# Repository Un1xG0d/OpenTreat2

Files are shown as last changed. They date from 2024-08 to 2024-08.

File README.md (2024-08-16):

<h1 align="center">
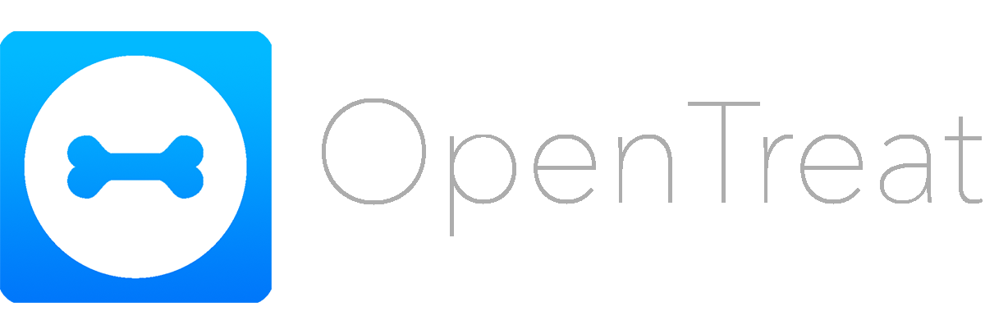
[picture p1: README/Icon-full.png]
  
</h1>

OpenTreat allows you to view and interact with your pets while not at home. 

Watch a live video stream of your pet from your smartphone or laptop, and remotely dispense treats with the push of a button.

This a complete rewrite of my original OpenTreat project found [here](https://github.com/Un1xG0d/OpenTreat-legacy).

## Overview
The treat dispenser system is built using a Raspberry Pi and 3D printed parts. When a user presses the button on the web app, it turns the servo motor for a certain number of seconds. This spins the middle piece and dispenses a section of treats into the bowl below.

## Parts needed
* Raspberry Pi
* SG90 servo (or any 360* servo motor)
* USB webcam
* 3D printer

## Physical assembly
1. Download and 3D print each STL listed in the `models` folder
	1. The recommended print settings are in the Resources section below
2. Assemble the parts using super glue
3. Hook up the 3 servo wires to the Raspberry Pi’s GPIO pins
	1. The proper pinout is in the Resources section below

## Device setup
1. Image your Raspberry Pi with [Raspbian](https://www.raspberrypi.com/software/)
2. Create a new user with the username `admin`
3. Configure your WiFi network settings
4. Enable OpenSSH

## Download the code
```
git clone https://github.com/Un1xG0d/OpenTreat.git ~/OpenTreat
cd ~/OpenTreat
```

## Install dependencies
```
sudo pip3 install -r requirements.txt
```

## Set up username and password
The web app uses HTTP Basic Auth to secure the video feed.

Create a `.env` file in the root directory and update the values accordingly:
```
USERNAME=test
PASSWORD=test
```

This will be your username & password to login to the web app.

## Automatic startup
Create a cronjob with `sudo crontab -e` to automatically set up and start the web app on boot.

```
@reboot /home/admin/OpenTreat/boot.sh
```

## Port forward the app
Make sure to change your router settings to allow a port forward of port 3000 to your Raspberry Pi. This is what makes the web app accessible to the internet.

## View the video stream
On your smartphone or laptop, browse to your router's external IP on port 3000 to view the video stream of your pets. Press the button to drop treats into your pets' bowl.

## Resources
### Recommended print settings
> Scale: 100%  
> Infill: 10%  
> Layer Height: 0.2  
> Speed: Standard  
> Supports: None

### RPi GPIO pinout
> Red wire - Pin 1 - 3v3 power  
> Black wire - Pin 6 - ground  
> Orange wire - Pin 11 - GPIO 17  

## Pictures & screenshots
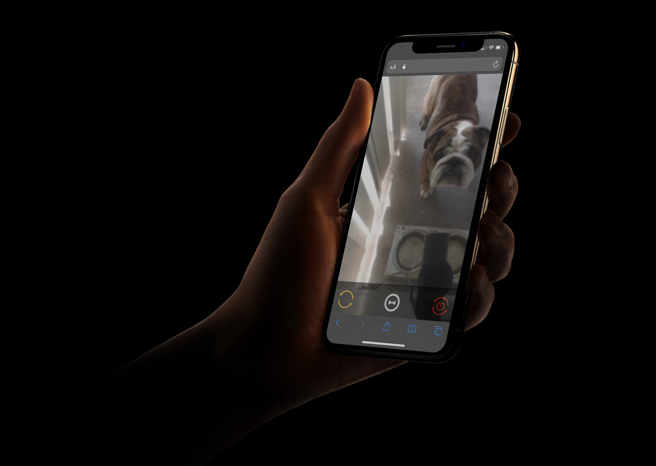
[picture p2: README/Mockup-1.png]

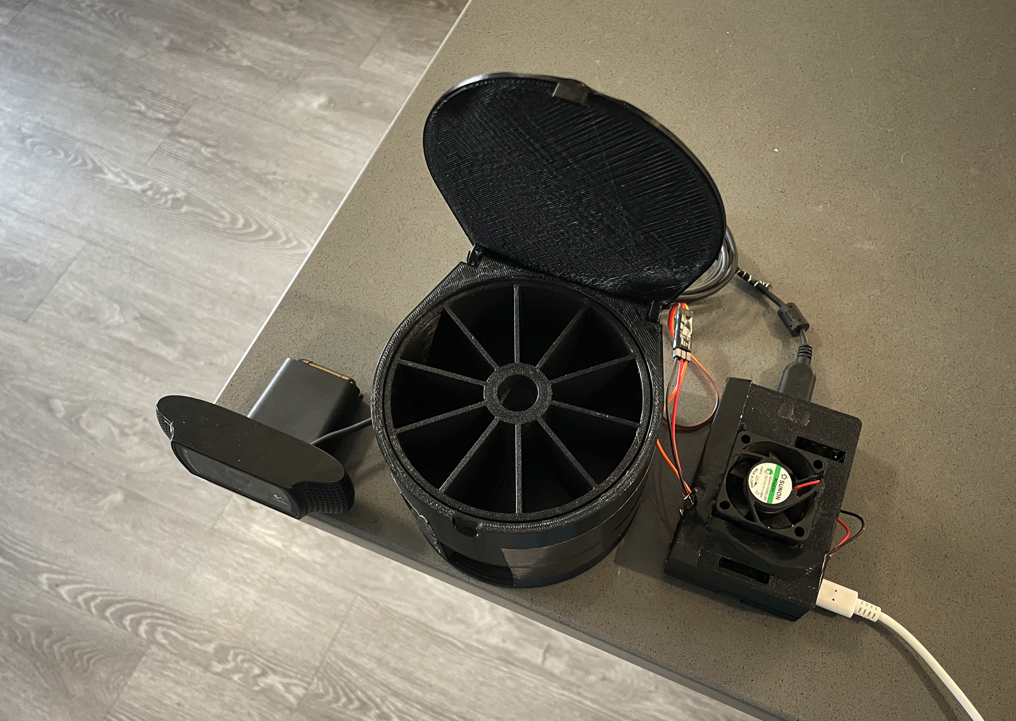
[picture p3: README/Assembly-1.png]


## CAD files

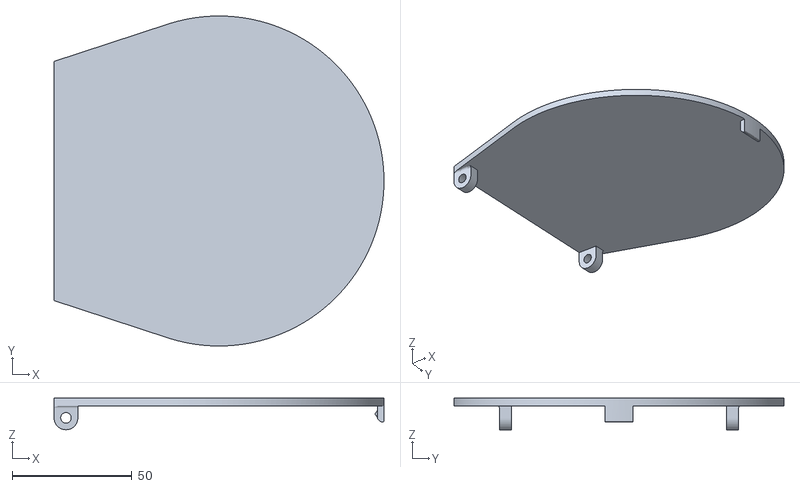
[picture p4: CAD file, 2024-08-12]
models/feeder_lid.stl
138.0 x 138.0 x 13.2

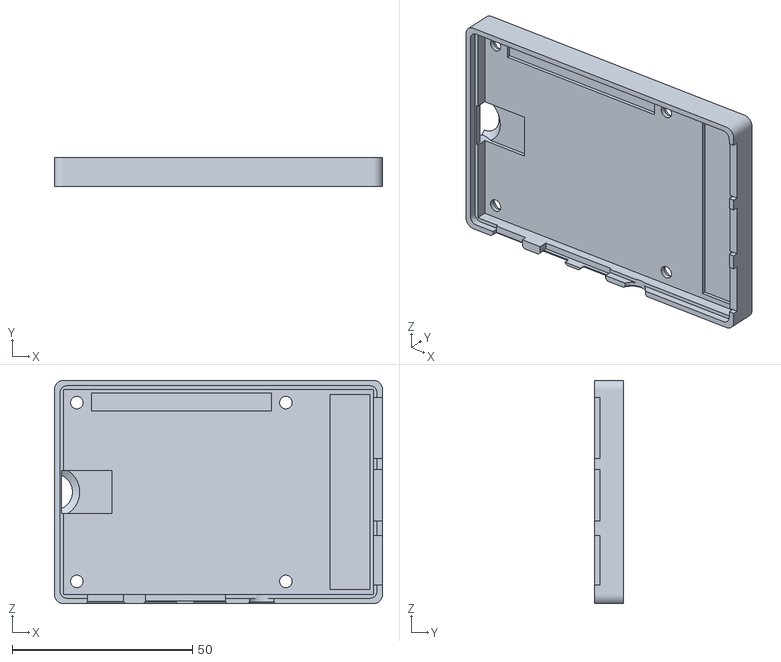
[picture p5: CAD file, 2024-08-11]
models/case_lower.stl
91.0 x 8.00 x 62.0

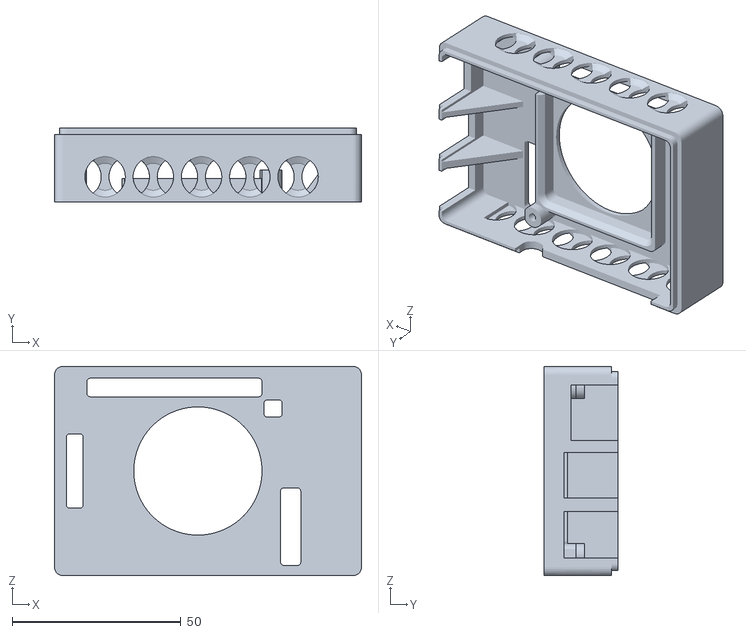
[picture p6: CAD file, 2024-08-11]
models/case_upper.stl
91.0 x 22.0 x 62.0

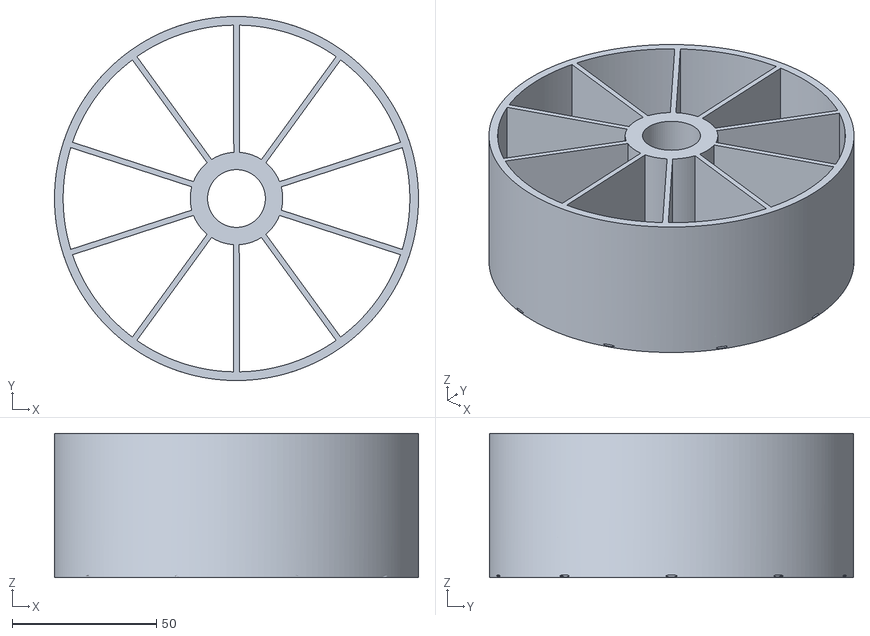
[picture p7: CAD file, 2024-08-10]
models/feeder_supply.stl
126.0 x 126.0 x 50.0

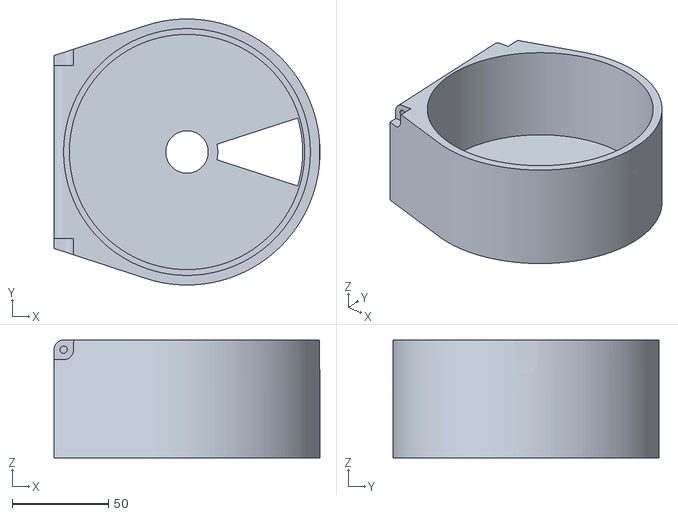
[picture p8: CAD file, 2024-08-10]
models/feeder_top.stl
138.0 x 138.0 x 61.2

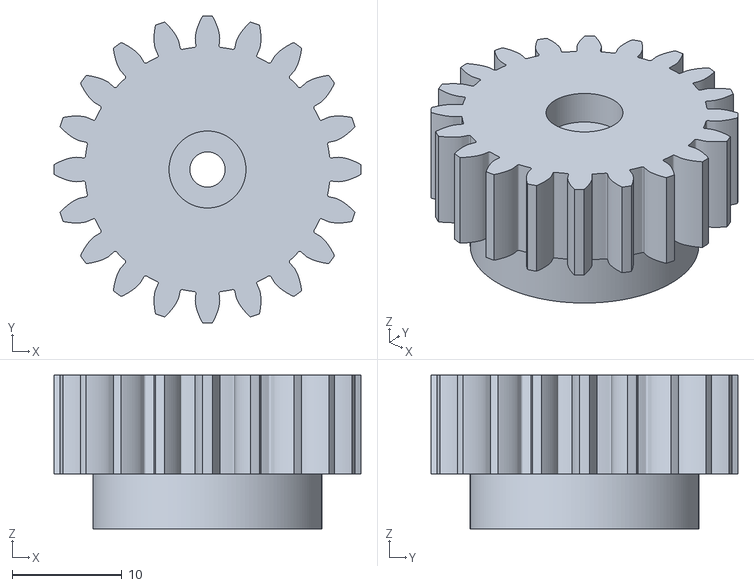
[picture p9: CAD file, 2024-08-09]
models/feeder_gear.stl
27.9 x 27.9 x 14.0

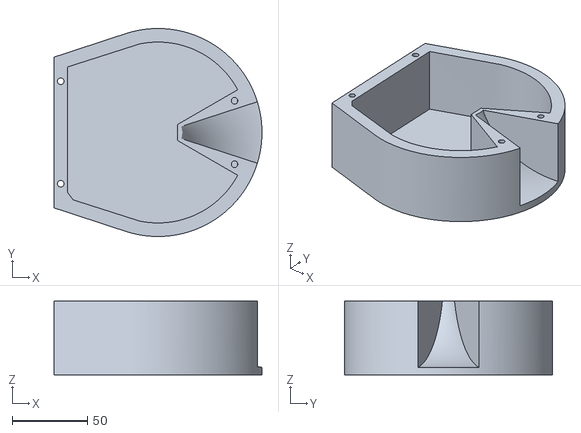
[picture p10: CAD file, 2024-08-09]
models/feeder_bottom.stl
138.0 x 138.0 x 49.0

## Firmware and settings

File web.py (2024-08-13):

import os
import pigpio
import time
from dotenv import load_dotenv
from flask import Flask, redirect, render_template, Response
from flask_basicauth import BasicAuth
from webcam import WebCam

load_dotenv()
app = Flask(__name__)
app.config["BASIC_AUTH_USERNAME"] = os.getenv("USERNAME")
app.config["BASIC_AUTH_PASSWORD"] = os.getenv("PASSWORD")
basic_auth = BasicAuth(app)
servo_pin = 17
pi = pigpio.pi()
pi.set_mode(servo_pin, pigpio.OUTPUT)

def generate(camera):
	while True:
		frame = camera.get_frame()
		yield (b"--frame\r\n"
			   b"Content-Type: image/jpeg\r\n\r\n" + frame + b"\r\n\r\n")

@app.after_request
def add_header(response):
	response.headers["Cache-Control"] = "no-store, must-revalidate"
	response.cache_control.max_age = 0
	response.cache_control.public = True
	return response

@app.route("/")
@basic_auth.required
def index():
	return render_template("index.html")

@app.route("/video_feed")
@basic_auth.required
def video_feed():
	return Response(generate(WebCam()), mimetype="multipart/x-mixed-replace; boundary=frame")

@app.route("/drop_treat")
@basic_auth.required
def drop_treat():
	pi.set_servo_pulsewidth(servo_pin, 1500) # stop servo
	time.sleep(0.5)
	pi.set_servo_pulsewidth(servo_pin, 1560) # spin servo
	time.sleep(0.5)
	pi.set_servo_pulsewidth(servo_pin, 1500) # stop servo
	return "DROPPED TREAT"

if __name__ == "__main__":
	app.run(host="0.0.0.0", port="3000", threaded=True)

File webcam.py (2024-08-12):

import os
import cv2
import threading
import time

try:
	from greenlet import getcurrent as get_ident
except ImportError:
	try:
		from thread import get_ident
	except ImportError:
		from _thread import get_ident

class CameraEvent(object):
	"""An Event-like class that signals all active clients when a new frame is available."""
	def __init__(self):
		self.events = {}

	def wait(self):
		"""Invoked from each client"s thread to wait for the next frame."""
		ident = get_ident()
		if ident not in self.events:
			# this is a new client
			# add an entry for it in the self.events dict
			# each entry has two elements, a threading.Event() and a timestamp
			self.events[ident] = [threading.Event(), time.time()]
		return self.events[ident][0].wait()

	def set(self):
		"""Invoked by the camera thread when a new frame is available."""
		now = time.time()
		remove = None
		for ident, event in self.events.items():
			if not event[0].isSet():
				# if this client"s event is not set, then set it
				# also update the last set timestamp to now
				event[0].set()
				event[1] = now
			else:
				# if the client's event is already set, it means the client did not process a previous frame
				# if the event stays set for more than 5 seconds, then assume the client is gone and remove it
				if now - event[1] > 5:
					remove = ident
		if remove:
			del self.events[remove]

	def clear(self):
		"""Invoked from each client's thread after a frame was processed."""
		self.events[get_ident()][0].clear()


class BaseCamera(object):
	thread = None  # background thread that reads frames from camera
	frame = None  # current frame is stored here by background thread
	last_access = 0  # time of last client access to the camera
	event = CameraEvent()

	def __init__(self):
		"""Start the background camera thread if it isn't running yet."""
		if BaseCamera.thread is None:
			BaseCamera.last_access = time.time()

			# start background frame thread
			BaseCamera.thread = threading.Thread(target=self._thread)
			BaseCamera.thread.start()

			# wait until first frame is available
			BaseCamera.event.wait()

	def get_frame(self):
		"""Return the current camera frame."""
		BaseCamera.last_access = time.time()

		# wait for a signal from the camera thread
		BaseCamera.event.wait()
		BaseCamera.event.clear()

		return BaseCamera.frame

	@staticmethod
	def frames():
		""""Generator that returns frames from the camera."""
		raise RuntimeError("Must be implemented by subclasses.")

	@classmethod
	def _thread(cls):
		"""Camera background thread."""
		frames_iterator = cls.frames()
		for frame in frames_iterator:
			BaseCamera.frame = frame
			BaseCamera.event.set()  # send signal to clients
			time.sleep(0)

			# if there hasn't been any clients asking for frames in the last 10 seconds then stop the thread
			if time.time() - BaseCamera.last_access > 10:
				frames_iterator.close()
				break
		BaseCamera.thread = None

class WebCam(BaseCamera):
	video_source = 0

	def __init__(self):
		super(WebCam, self).__init__()

	@staticmethod
	def set_video_source(source):
		WebCam.video_source = source

	@staticmethod
	def frames():
		camera = cv2.VideoCapture(WebCam.video_source)
		if not camera.isOpened():
			raise RuntimeError("Could not start camera.")

		while True:
			# read current frame
			_, img = camera.read()

			# encode as a jpeg image and return it
			yield cv2.imencode(".jpg", img)[1].tobytes()

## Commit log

2024-08-09 commit initial code
    [bottom.stl, gear.stl, lid.stl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]
2024-08-10 update models
    [supply.stl, top.stl]
2024-08-10 remove lid model
    [lid.stl]
2024-08-10 update README with recommended print scale
2024-08-10 update button styles
2024-08-10 remove PNG for treat button
2024-08-11 add and update model files
    [case_lower.stl, case_upper.stl, feeder_bottom.stl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]
2024-08-12 add try statement for camera frame functions
2024-08-12 remove try statement for camera frame functions
2024-08-12 revert video feed generation
    [web.py]
2024-08-12 cast PID as string
2024-08-12 disable scrolling on mobile devices
2024-08-12 remove watermark from lid model
    [feeder_lid.stl]
2024-08-15 update recommended print settings
2024-08-16 update README file with assembly picture
